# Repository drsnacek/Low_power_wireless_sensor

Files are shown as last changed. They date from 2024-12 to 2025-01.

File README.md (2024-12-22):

# Low power wireless sensor
The intention is to build up a sensor powered by the batteries and wirelessly communicate with a server.

The first version is based on ESP8266 with the wifi connection to the server.
The DHT11 temprature/humidity sensor is powered through a NPN tranzistor that is controlled via the SW to unconnect the sensor power when the ESP is in the deep standby mode. MCP1700 is used to provide 3.3V for ESP, C2 is powering the ESP power peaks. TP4056 battery charger with the battery protection (BMS) built in is used togerther with Li-ion 18650 4.7V battery. R8 and R7 are a divider for measuring the battery state.

All components should provide very low power consumption in the deep standby mode to prolong the battery charnging needs as much as possible.

Component	Standby(µA)	Active(mA)

TP4056	50 µA (with LED: 2mA)	N/A
MCP1700	1,6 µA	250 mA (max)
ESP-12F	20-40 µA (deep sleep)	70-150 mA (Wi-Fi)
BMS	10 µA	N/A
Total energy consumption (standby)	~80-100 µA

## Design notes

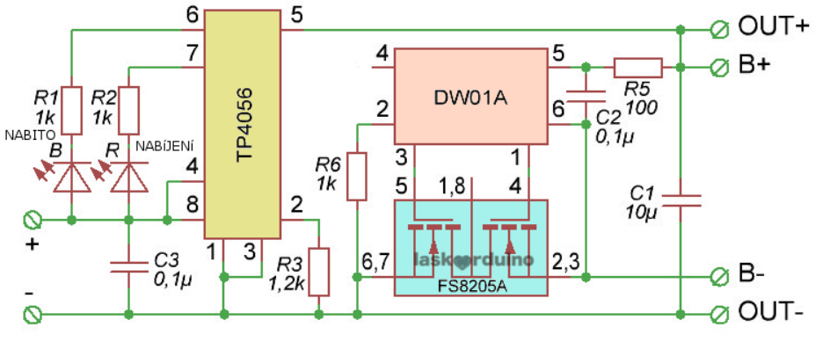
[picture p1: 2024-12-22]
TP4056_charger.bmp

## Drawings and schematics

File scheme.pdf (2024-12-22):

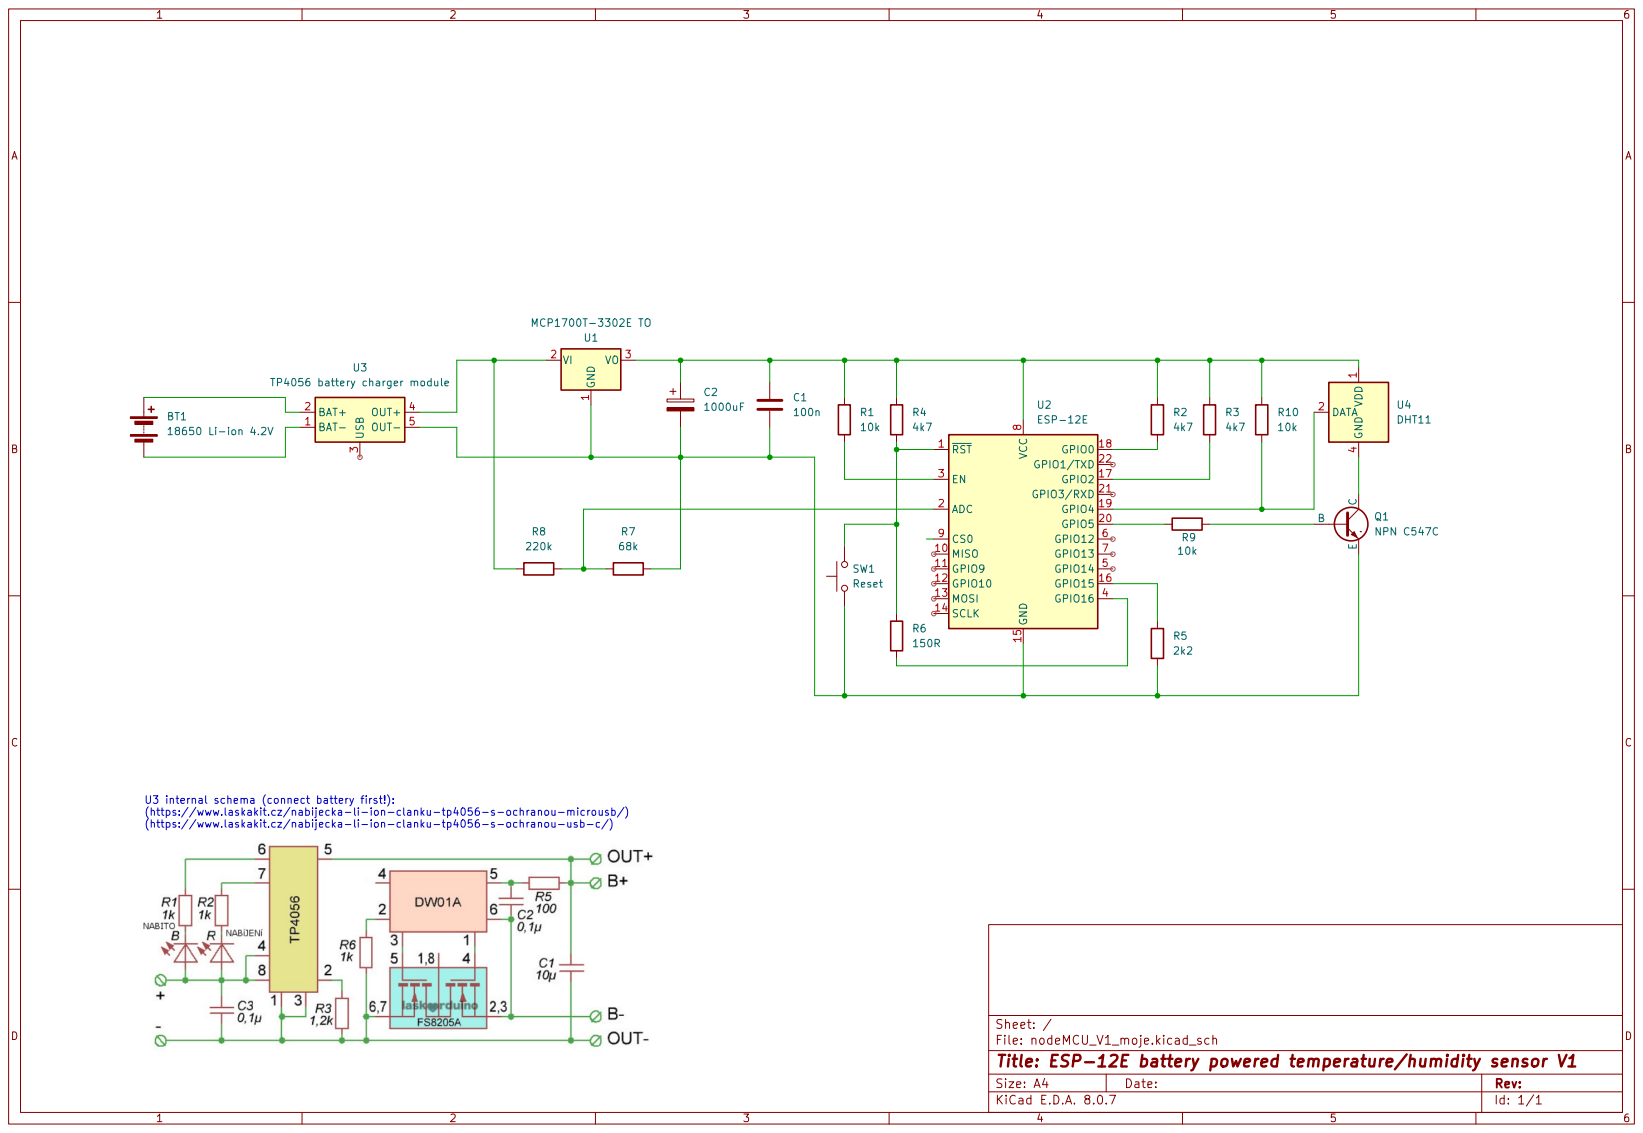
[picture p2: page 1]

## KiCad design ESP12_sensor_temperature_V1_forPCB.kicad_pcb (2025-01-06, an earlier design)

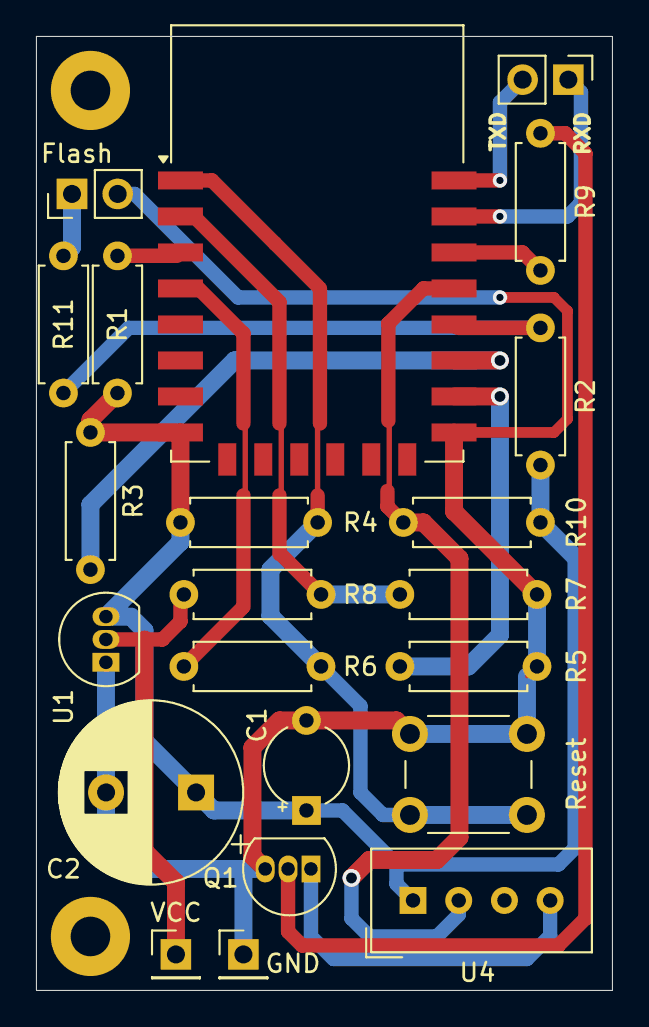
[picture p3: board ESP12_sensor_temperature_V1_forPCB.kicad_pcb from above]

Board: 2 copper layers, 32.0 x 53.0 mm, 22 parts (0 on the bottom side), 17 nets.

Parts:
C1: 100n; CP_Radial_Tantal_D4.5mm_P5.00mm
C2: 1000uF; CP_Radial_D10.0mm_P5.00mm
Flash: Close for Flash; PinHeader_1x02_P2.54mm_Vertical
GND: GND; PinHeader_1x01_P2.54mm_Vertical
J6: TXD RXD; PinHeader_1x02_P2.54mm_Vertical
Q1: NPN C547C; TO-92L_Inline
R1, R9, R10: 10k; R_Axial_DIN0207_L6.3mm_D2.5mm_P7.62mm_Horizontal
R2, R3, R4: 4k7; R_Axial_DIN0207_L6.3mm_D2.5mm_P7.62mm_Horizontal
R5: 2k2; R_Axial_DIN0207_L6.3mm_D2.5mm_P7.62mm_Horizontal
R6: 150R; R_Axial_DIN0207_L6.3mm_D2.5mm_P7.62mm_Horizontal
R7: 68k; R_Axial_DIN0207_L6.3mm_D2.5mm_P7.62mm_Horizontal
R8: 220k; R_Axial_DIN0207_L6.3mm_D2.5mm_P7.62mm_Horizontal
R11: 120R; R_Axial_DIN0207_L6.3mm_D2.5mm_P7.62mm_Horizontal
Reset: Reset; SW_PUSH_6mm_H4.3mm
U1: MCP1700T-3302E TO; TO-92_Inline
U2: ESP-12E
U4: DHT11; Aosong_DHT11_5.5x12.0_P2.54mm
VCC: VCC; PinHeader_1x01_P2.54mm_Vertical

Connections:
GND: C1.2, C2.2, Flash.2, GND.1, Q1.3 (E), R5.2, R7.2, Reset.1, U1.1 (GND), U2.15 (GND)
unnamed: Flash.1, R11.2
unnamed: J6.1, U2.21 (GPIO3/RXD)
unnamed: J6.2, U2.22 (GPIO1/TXD)
unnamed: Q1.2 (B), R9.2
unnamed: Q1.1 (C), U4.4 (GND)
unnamed: C1.1, C2.1, R1.1, R2.1, R3.1, R4.1, R10.1, U1.3 (VO), U2.8 (VCC), U4.1 (VDD)
unnamed: R7.1, R8.2, U2.2 (ADC)
unnamed: R1.2, U2.3 (EN)
unnamed: R2.2, R11.1, U2.18 (GPIO0)
unnamed: R3.2, U2.17 (GPIO2)
unnamed: R10.2, U2.19 (GPIO4), U4.2 (DATA)
unnamed: R9.1, U2.20 (GPIO5)
unnamed: R5.1, U2.16 (GPIO15)
unnamed: R6.2, U2.4 (GPIO16)
unnamed: R4.2, R6.1, Reset.2, U2.1 (~RST)
VCC: R8.1, U1.2 (VI), VCC.1
